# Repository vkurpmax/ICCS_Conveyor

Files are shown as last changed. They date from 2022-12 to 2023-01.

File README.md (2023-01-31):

# ICCS_Conveyor
Integrated Conveyor Control System (ICCS) was my project on Mechatronics Day 2022.
I tried to combined two different projects together, Conveyor Robot and Manipulator Robot.

## History
This project coming from two different projects:
1. Manipulator Robot <br>
It was created by students as a final project and then developed by John Michael Adiputra and Andi Baso in 2017.

2. Conveyor Robot <br>
It was created by Handrisumanto's team for Mechatronic's Day 2020

## Microcontrollers
This project used 3 Microcontrollers:

For Conveyor:
1. NodeMCU ESP8266 Wifi <br>
More about NodeMCU ESP8266 can be read [here](https://randomnerdtutorials.com/esp8266-pinout-reference-gpios/)
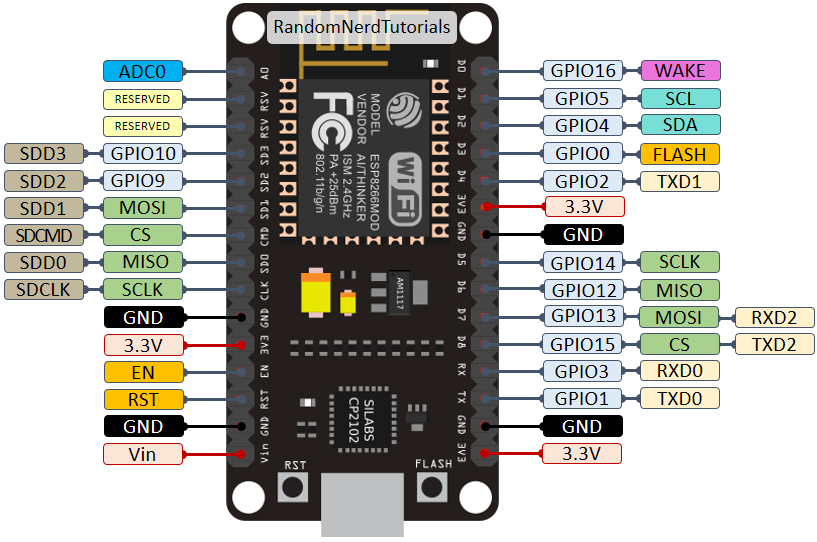
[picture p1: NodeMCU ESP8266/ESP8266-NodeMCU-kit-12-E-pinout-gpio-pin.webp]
NodeMCU ESP8266 GPIO Diagram

2. Arduino Uno

For Manipulator Robot:
1. Arduino Mega

## Software used
1. Arduino IDE — Download [here](https://www.arduino.cc/en/software)
2. Blynk (for mobile, download from Play Store)
3. Fritzing — For Circuit Diagram Design

## Other device
1. Power Supply 12V adaptor to Arduino Uno (1A is enough)

## My Team
- Putu Herdy Kurniawan
- Agus
- Indri Puspita
- Risnawati
- Aan Darmawan

## Youtube
[Youtube](https://youtu.be/FnN2X-vGAT0)

## Circuit Diagram
### Conveyor Circuit Diagram
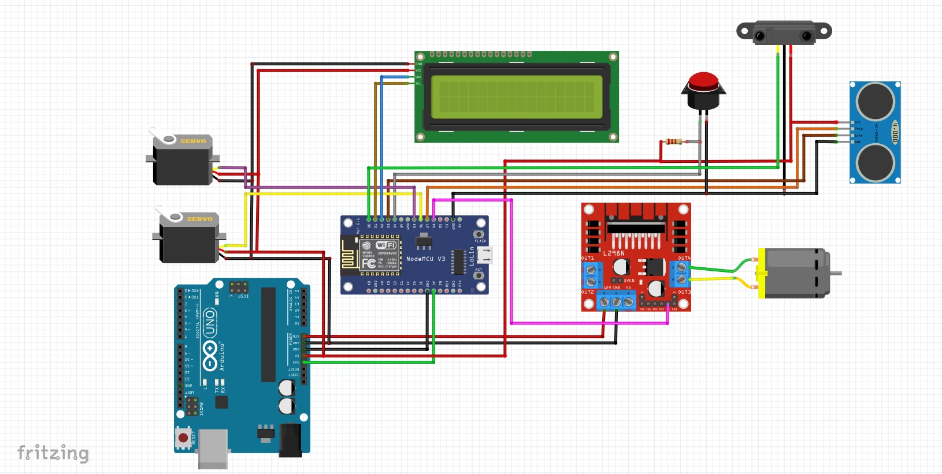
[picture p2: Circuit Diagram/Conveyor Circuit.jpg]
Conveyor Circuit Diagram


### Conveyor IoT using Blynk
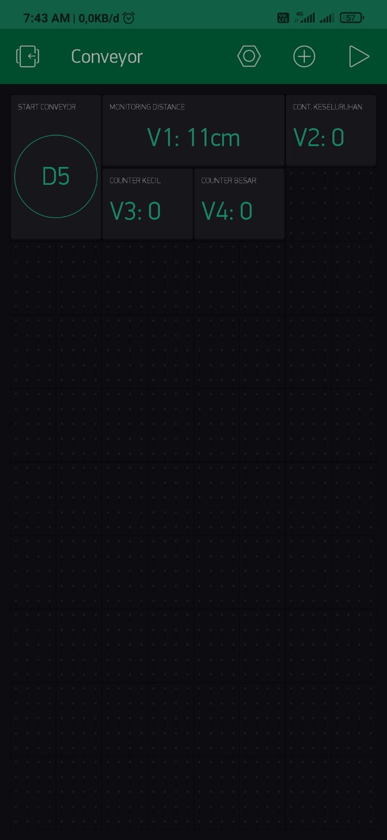
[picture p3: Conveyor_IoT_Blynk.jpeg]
Conveyor Circuit Diagram


## License
[MIT License](LICENSE)

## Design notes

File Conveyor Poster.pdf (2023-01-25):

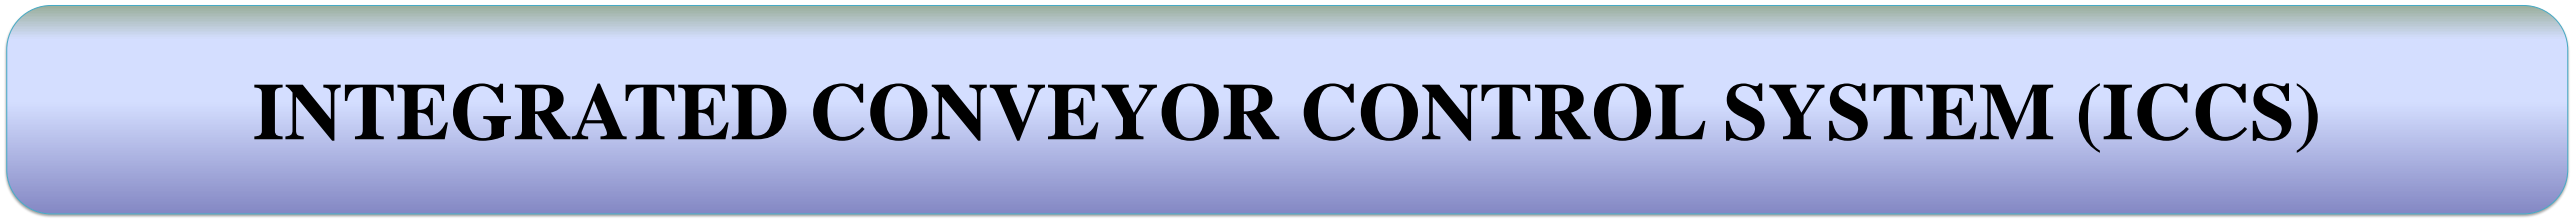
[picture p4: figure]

Putu Herdy Kurniawan¹
, Agus

1
, Aan Darmawan

1
, Indri Puspita

1
, Risnawati

1
Dr. Eng. Akhmad Taufik, S.T., M.T.

1
,Imran Habriansyah, S.ST., M.T.

1
1Program Studi D4 Teknik Mekatronika, Jurusan Teknik Mesin, Politeknik Negeri Ujung Pandang, Indonesia

### 1. Latar Belakang

## INTEGRATED CONVEYOR CONTROL SYSTEM (ICCS)

### 2. Tujuan

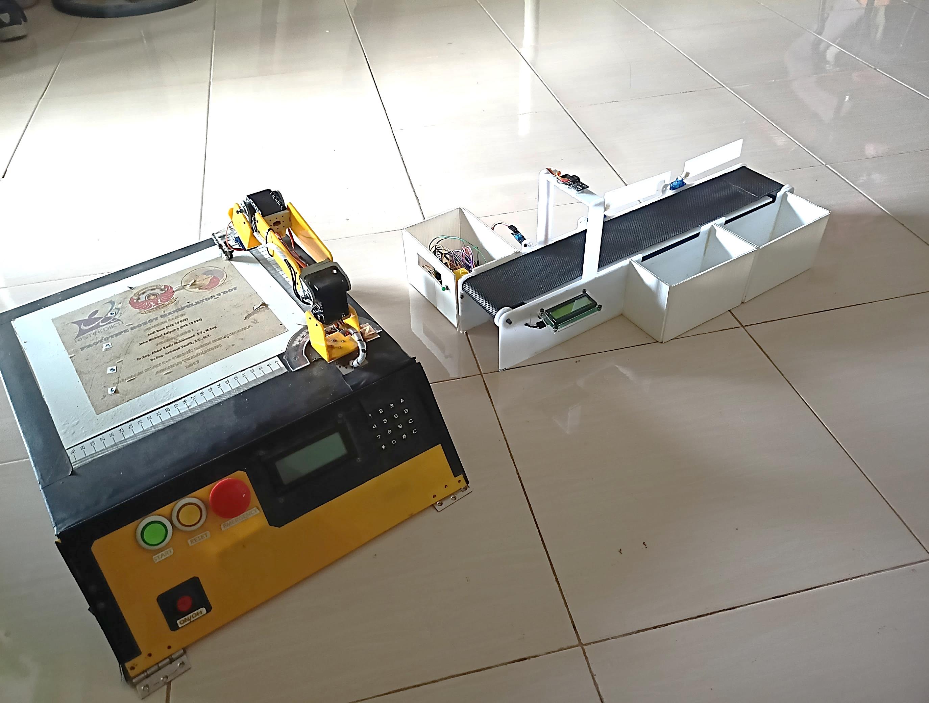
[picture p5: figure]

### 7. Kesimpulan

Seiring pesatnya perkembangan teknologi di bidang industri, khususnya dalam proses manufaktur atau produksi menyebabkan peningkatan kebutuhan akan conveyor dan robot manipulator. Conveyor merupakan suatu sistem mekanik yang berfungsi untuk memobilisasi objek yang yang masif, sedangkan robot manipulator bekerja untuk memindahkan objek dengan syarat atau situasi khusus. Pada sistem ini, kami menggunakan robot manipulator yang diintegrasikan dengan conveyor untuk memobilisasi objek menuju bagian sortir. Objek akan diklasifikasikan menjadi dua, yaitu: besar dan kecil.

a. Memahami prinsip kerja serta proses integrasi sistem robot manipulator ke dalam sistem conveyor..

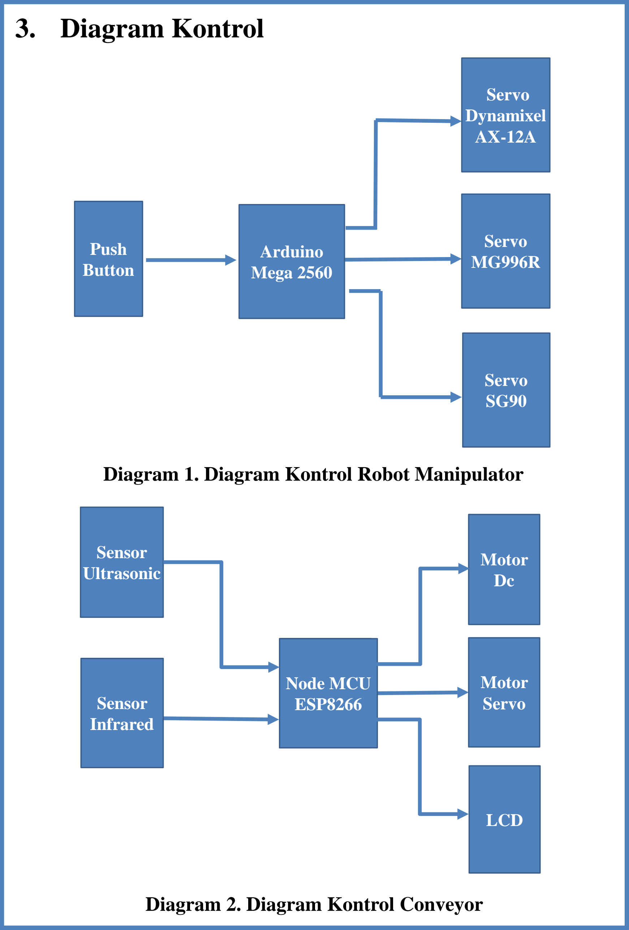
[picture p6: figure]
3. Diagram Kontrol; Diagram 2. Diagram Kontrol Conveyor; Arduino Uno; LCD; Motor Servo; Node MCU ESP8266; Motor Dc; Sensor Ultrasonic; Sensor Infrared; Push Button; Arduino Mega 2560; Servo Dynamixel AX-12A; Servo MG996R; Servo SG90

### 4. Rangkaian Elektronik

### 6. Prinsip Kerja

Gambar 2. Prototipe Integrated Conveyor Control Sistem

### 5. Tampilan Fisik

a.

Dari hasil dan pembahasan Pengembangan Prototipe Integrated Conveyor Control System, maka dapat disimpulkan:

b.

Pemindahan letak LCD 16x2 pada conveyor dari bagian control box (samping) ke bagian depan conveyor meningkatkan nilai estetika serta fungsional, sehingga mempermudah pembacaan parameter sorting.
Sistem robot manipulator yang telah lama tidak digunakan menyebabkan terjadinya beberapa kerusakan, seperti kabel serta rangkaian yang terputus akibat lapuk serta karatan.
Hasil | simulasi | dan | eksperimen | integrasi | kedua | sistem
menunjukkan bahwa integrated system dapat berjalan dan saling melengkapi, walaupun masih terdapat beberapa bug atau error pada sistem.

c.

Robot manipulator mengambil objek pada koordinat yang telah ditentukan kemudian memindahkannya ke atas roller conveyor. Objek dideteksi oleh IR sensor yang berfungsi untuk menghitung jumlah objek sehingga mengaktifkan trigger ultrasonic yang akan menentukan klasifikasi objek untuk kemudian dilakukan sorting dengan menggunakan servo.

Diagram 1. Diagram Kontrol Robot Manipulator

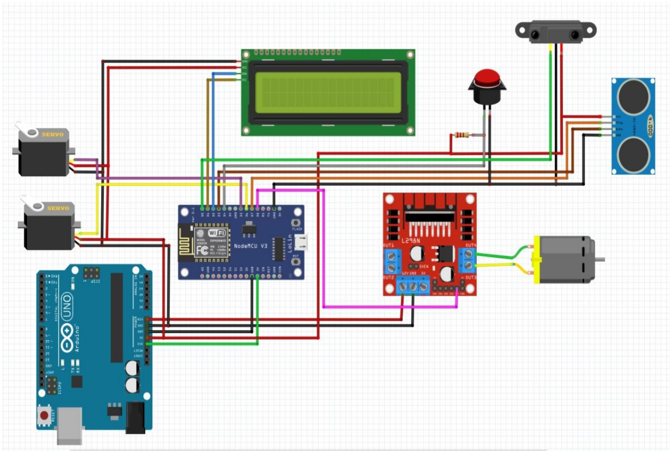
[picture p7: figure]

Gambar 1. Rangkaian Elektronik ICCS

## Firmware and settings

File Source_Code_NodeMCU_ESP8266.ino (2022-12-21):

#include <ESP8266WiFi.h>
#include <BlynkSimpleEsp8266.h>
#include <LiquidCrystal_I2C.h>
#include <NewPing.h>
#include <Servo.h>
#include <Wire.h>

LiquidCrystal_I2C lcd(0x27, 16, 2);

Servo servo1;
Servo servo2;

#define trigPin 13                                // D7 NodeMCU ESP8266
#define echoPin 0                                 // D3 NodeMCU ESP8266
#define MAX_DISTANCE 200
#define BLYNK_PRINT Serial

NewPing sonar(trigPin, echoPin, MAX_DISTANCE);

int IN4 = 15;                                     // D8 NodeMCU ESP8266
const int tombol = 2;                             // D4 NodeMCU ESP8266
int countertombol = 0;
int count = 0;                                    // Jumlah Jeruk
int countkecil = 0;
int countbesar = 0;
long duration;
int distance;
int val2;

char auth[] = "D2z26gaorTO98bRkWelsW-mheQCpFkXx"; // Change to your Blynk Authentication Token
char ssid[] = "Vkurpmax";                         // Change to your Network SSID
char pass[] = "lumos maxima";                     // Change to your Network Password

BlynkTimer timer;

void myTimerEvent()
{
  Blynk.virtualWrite(V1,distance);
  Blynk.virtualWrite(V2,count);
  Blynk.virtualWrite(V3,countkecil);
  Blynk.virtualWrite(V4,countbesar);
}

void setup()
{
  Serial.begin(9600);
  Blynk.begin(auth, ssid, pass);
  timer.setInterval(1000L, myTimerEvent);

  pinMode(IN4, OUTPUT);
  pinMode(tombol, INPUT_PULLUP);  // D4 Pushbutton
  pinMode(16, INPUT);             // D0 NodeMCU ESP8266 for IR
  pinMode(trigPin,OUTPUT);        // Trig pin
  pinMode(echoPin,INPUT);         // Echo pin

  servo1.attach(12);              // D6 NodeMCU ESP8266
  servo2.attach(14);              // D5 NodeMCU ESP8266

  servo1.write(105);
  servo2.write(93);

  lcd.begin();
  lcd.setCursor(0,0);
  lcd.print("     ORANGE    ");
  lcd.setCursor(0,1);
  lcd.print("SORTING CONVEYOR");
  delay(3000);
  lcd.clear();
  lcd.setCursor(0,0);
  lcd.print("  PLEASE PUSH  ");
  lcd.setCursor(0,1);
  lcd.print("  START BUTTON  ");
}

void loop()
{ 
  Blynk.run();
  timer.run();
  pushbutton();
  IR1();
  bacaultra();
}

void pushbutton()
{
  if (digitalRead(tombol) == LOW)
  {
    countertombol++;
    delay(500);
    if (countertombol == 1)
    { 
      digitalWrite(IN4, HIGH);
      lcd.clear();
      lcd.setCursor(0,0);
      lcd.print("    CONVEYOR    ");
      lcd.setCursor(0,1);
      lcd.print("       ON       ");
    }
    if (countertombol == 2)
    { 
      digitalWrite(IN4, LOW);
      servo1.write(105);
      servo2.write(93);
      countertombol = 0;
      count = 0;
      countkecil = 0;
      countbesar = 0;

      lcd.clear();
      lcd.setCursor(0,0);
      lcd.print("    CONVEYOR    ");
      lcd.setCursor(0,1);
      lcd.print("      OFF");
      delay(3000);

      lcd.clear();
      lcd.setCursor(0,0);
      lcd.print("     THANK     ");
      lcd.setCursor(0,1);
      lcd.print("      YOU      ");
      delay(3000);

      lcd.clear();
      lcd.setCursor(0,0);
      lcd.print("  PLEASE  PUSH  ");
      lcd.setCursor(0,1);
      lcd.print("  START BUTTON  ");
    }
  }
}

void IR1()
{
  val2 = digitalRead(16);
  if (val2 == LOW && countertombol == 1)
  {
    count++;
    lcd.clear();
    lcd.setCursor(0,0);
    lcd.print("Jumlah Jeruk =");
    lcd.print(count);
    lcd.setCursor(0,1);
    lcd.print("Besar=");
    lcd.print(countbesar);
    lcd.print(" Kecil=");
    lcd.print(countkecil);
    
    digitalWrite(IN4,LOW);  // Motor OFF
    delay(1000);
    digitalWrite(IN4,HIGH); // Motor ON 
  }
}

void bacaultra(){ 
  digitalWrite(trigPin, LOW); 
  delayMicroseconds(2); 
  digitalWrite(trigPin, HIGH);
  delayMicroseconds(10); 
  digitalWrite(trigPin, LOW);
  duration = pulseIn(echoPin, HIGH);
  distance = (duration/2) / 29.1;
  delay (300);
  Serial.println(distance);
  
  if(distance>=6 && distance <9 && countertombol == 1)  // Kecil
  {
 
   countkecil++;
   lcd.clear();
   lcd.setCursor(0,0);
   lcd.print("Jumlah Jeruk =");
   lcd.print(count);
   lcd.setCursor(0,1);
   lcd.print("Besar=");
   lcd.print(countbesar);
   lcd.print(" Kecil=");
   lcd.print(countkecil);

   digitalWrite(IN4,LOW); // Motor OFF
   delay(1000);
   digitalWrite(IN4,HIGH);
   servo1.write(30);
   delay(4500);
   servo1.write(105);
  }
   if(distance<=5 && distance>=1 &&countertombol == 1)  // Besar
  {
    countbesar++;
    lcd.clear();
    lcd.setCursor(0,0);
    lcd.print("Jumlah Jeruk =");
    lcd.print(count);
    lcd.setCursor(0,1);
    lcd.print("Besar=");
    lcd.print(countbesar);
    lcd.print(" Kecil=");
    lcd.print(countkecil);

   digitalWrite(IN4,LOW); // Motor OFF
   delay(1000);
   digitalWrite(IN4,HIGH);
   servo2.write(10);
   delay(4500);
   servo2.write(93);
  } 
}

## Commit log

2022-12-20 Update Arduino IDE download link
2022-12-20 Upload Conveyor Circuits
    [Conveyor Circuit.fzz]
2022-12-20 add image circuit readme.md
2022-12-26 add power supply
2023-01-25 Upload Conveyor poster
2023-01-31 Edit Readme.md add Conveyor IoT
